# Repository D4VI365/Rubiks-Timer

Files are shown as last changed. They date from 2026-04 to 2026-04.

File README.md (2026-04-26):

# Rubiks Timer
I'm gonna build a timer to use with my rubiks cube, it will be powered by an esp32 and it will host a webpage to view the times registered.

The device is powered by a rechargable 2000mAh LiPo battery, it shows the time to the millisecond and the status of the timer with a strip of neopixels. There also are two phisical buttons for an easier access to deleting the time and adding a penality.

Full timer:
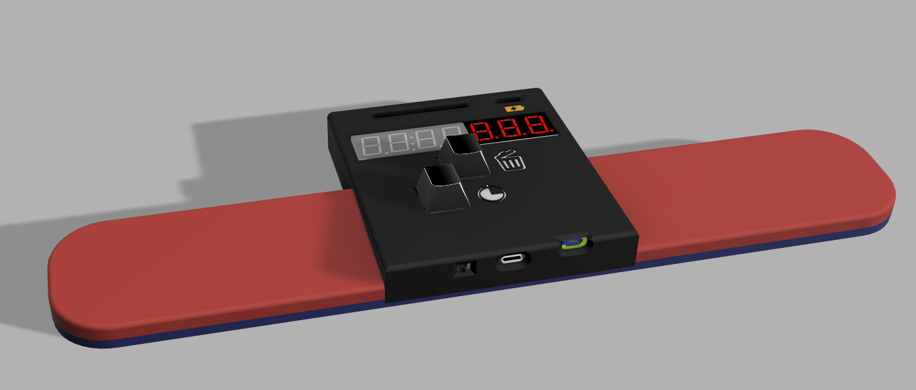
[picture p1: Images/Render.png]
Render


Electrical scheme:
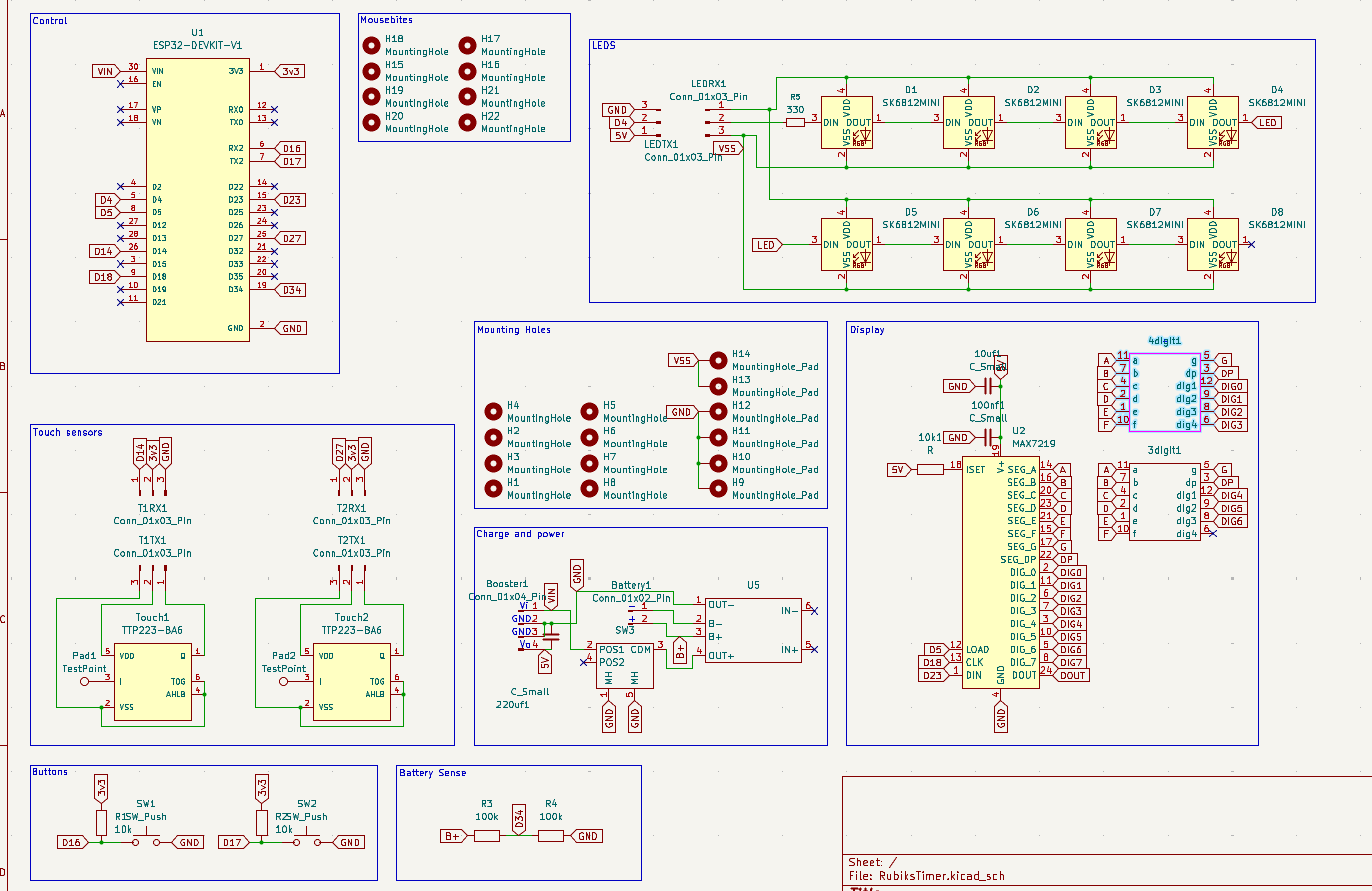
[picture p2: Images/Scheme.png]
Scheme


PCB layout: 
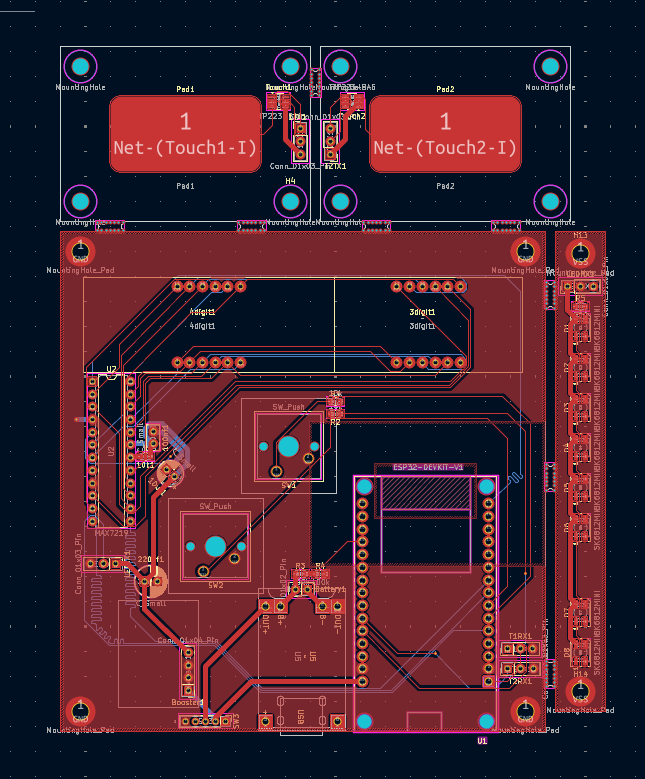
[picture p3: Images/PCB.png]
PCB


Inernal components placement:
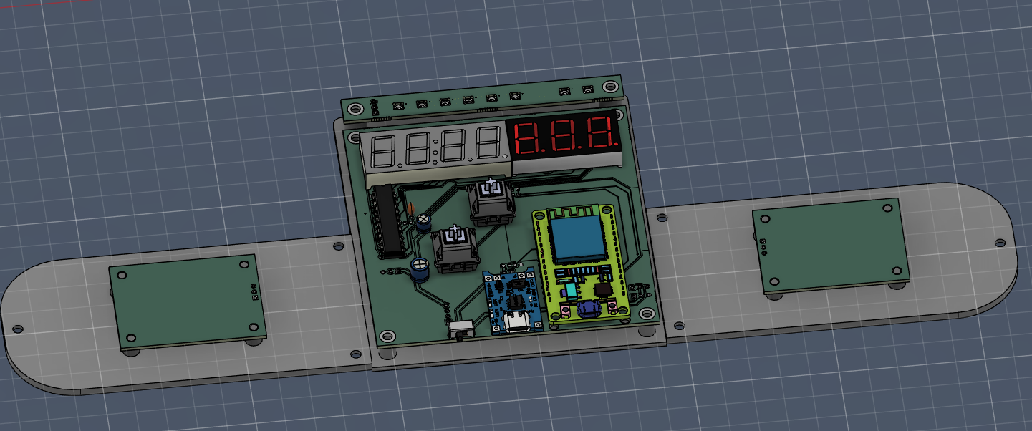
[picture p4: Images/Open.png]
Open


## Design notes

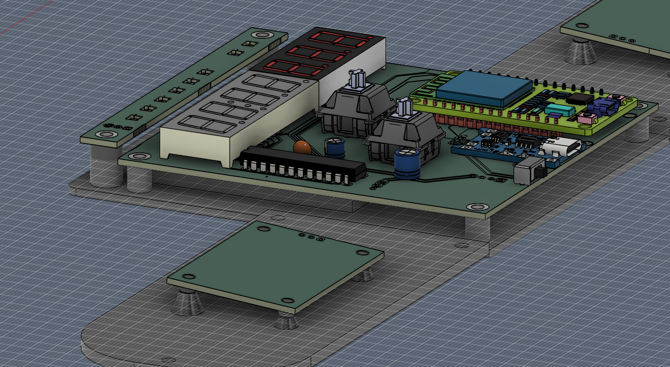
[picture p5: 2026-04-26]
Images/Side.png

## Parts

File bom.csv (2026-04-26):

Name | Purpose | Quantity | Total Cost (USD) | Link | Distributor
PCB | Holding the components | 1 | 10.00 | https://jlcpcb.com | JLCPCB
Neopixels | showing the battery and timer status | 5 | 4.02 | https://it.aliexpress.com/item/1005007576573654.html | Aliexpress
switches | Deleting times and adding penalities without opening the web page | 2 | 6.22 | https://it.aliexpress.com/item/1005007983672026.html | Aliexpress
505060 200mAh battery | powering the circuit off the grid | 1 | 11.26 | https://www.aliexpress.com/item/1005009145417769.html?spm=a2g0o.cart.0.0.685518fcIZnX3J&mp=1 | Aliexpress
TTP223 chip | creating the touch pads | 2 | 1.89 | https://www.aliexpress.com/item/1005006232332977.html?spm=a2g0o.cart.0.0.685518fcIZnX3J&mp=1 | Aliexpress
ESP32 | Controlling everithing | 1 | 4.71 | https://www.aliexpress.com/item/1005005953505528.html?spm=a2g0o.cart.0.0.685518fcIZnX3J&mp=1 | Aliexpress
2 digit 7segment display | Showing up to the cents of second | 1 | 1.70 | https://www.aliexpress.com/item/1005009575068782.html?spm=a2g0o.cart.0.0.685518fcIZnX3J&mp=1 | Aliexpress
MAX7219 | Controlling the 7segment displays | 1 | 3.88 | https://www.aliexpress.com/item/1005009392438551.html?spm=a2g0o.cart.0.0.685518fcIZnX3J&mp=1 | Aliexpress
5V boost module | getting 5V from the battry to power the ttp223 and the displays | 1 | 2.86 | https://www.aliexpress.com/item/1005006019647964.html?spm=a2g0o.cart.0.0.685518fcIZnX3J&mp=1 | Aliexpress
on off switch | cutting the circuit and preventing battery fading | 1 | 2.13 | https://www.aliexpress.com/item/1005010458551063.html?spm=a2g0o.cart.0.0.685518fcIZnX3J&mp=1 | Aliexpress
4digit 7segment display | showing minutes and seconds | 1 | 2.96 | https://www.aliexpress.com/item/1005009575068782.html?spm=a2g0o.cart.0.0.685518fcIZnX3J&mp=1 | Aliexpress
tp4056 | battery charging module | 1 | 1.54 | https://www.aliexpress.com/item/1005006043031985.html?spm=a2g0o.cart.0.0.685518fcIZnX3J&mp=1 | Aliexpress
smd resistors | Pull-up, protection and battery sensing circuit | 1 | 3.45 | https://www.aliexpress.com/item/1005002753179336.html?spm=a2g0o.cart.0.0.685518fcIZnX3J&mp=1 | Aliexpress
100nF capacitor | decoupling capacitors | 3 | 2.56 | https://www.aliexpress.com/item/1005007540183265.html?spm=a2g0o.cart.0.0.685518fcIZnX3J&mp=1 | Aliexpress

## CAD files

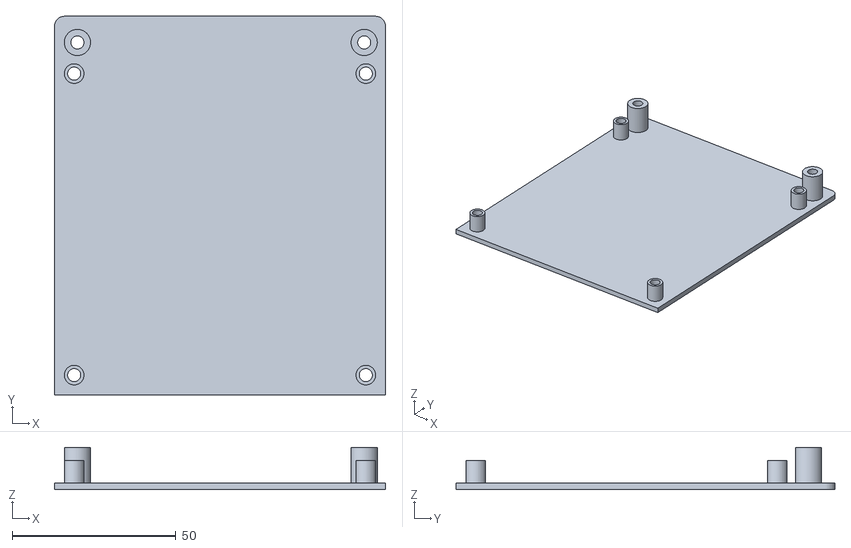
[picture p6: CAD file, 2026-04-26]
CAD/MainBottom.stl
101.0 x 115.5 x 13.0

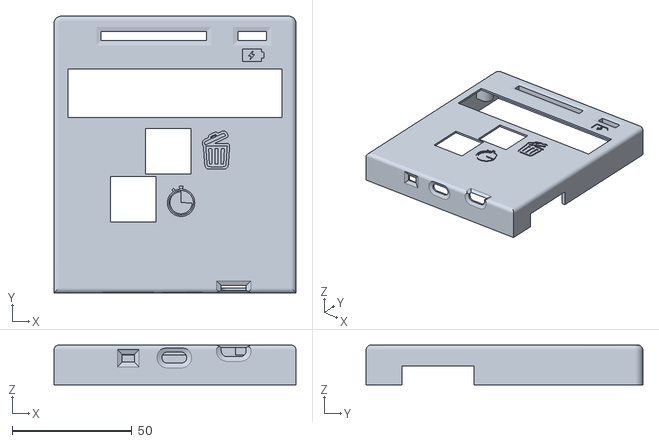
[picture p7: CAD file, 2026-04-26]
CAD/MainTop.stl
101.0 x 115.5 x 16.6

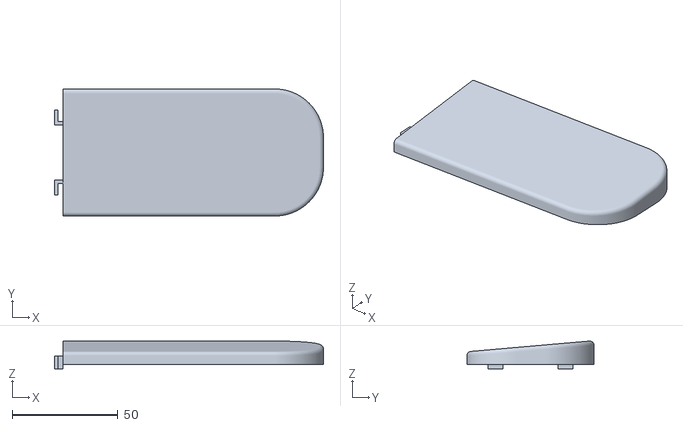
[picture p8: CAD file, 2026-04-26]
CAD/RightCAP.stl
127.0 x 60.0 x 13.2

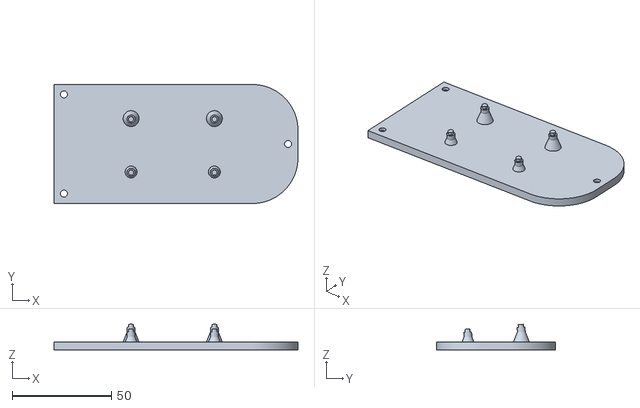
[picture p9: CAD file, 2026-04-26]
CAD/RightBottom.stl
123.0 x 60.0 x 12.9

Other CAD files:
CAD/LeftCAP.stl
CAD/LeftBottom.stl

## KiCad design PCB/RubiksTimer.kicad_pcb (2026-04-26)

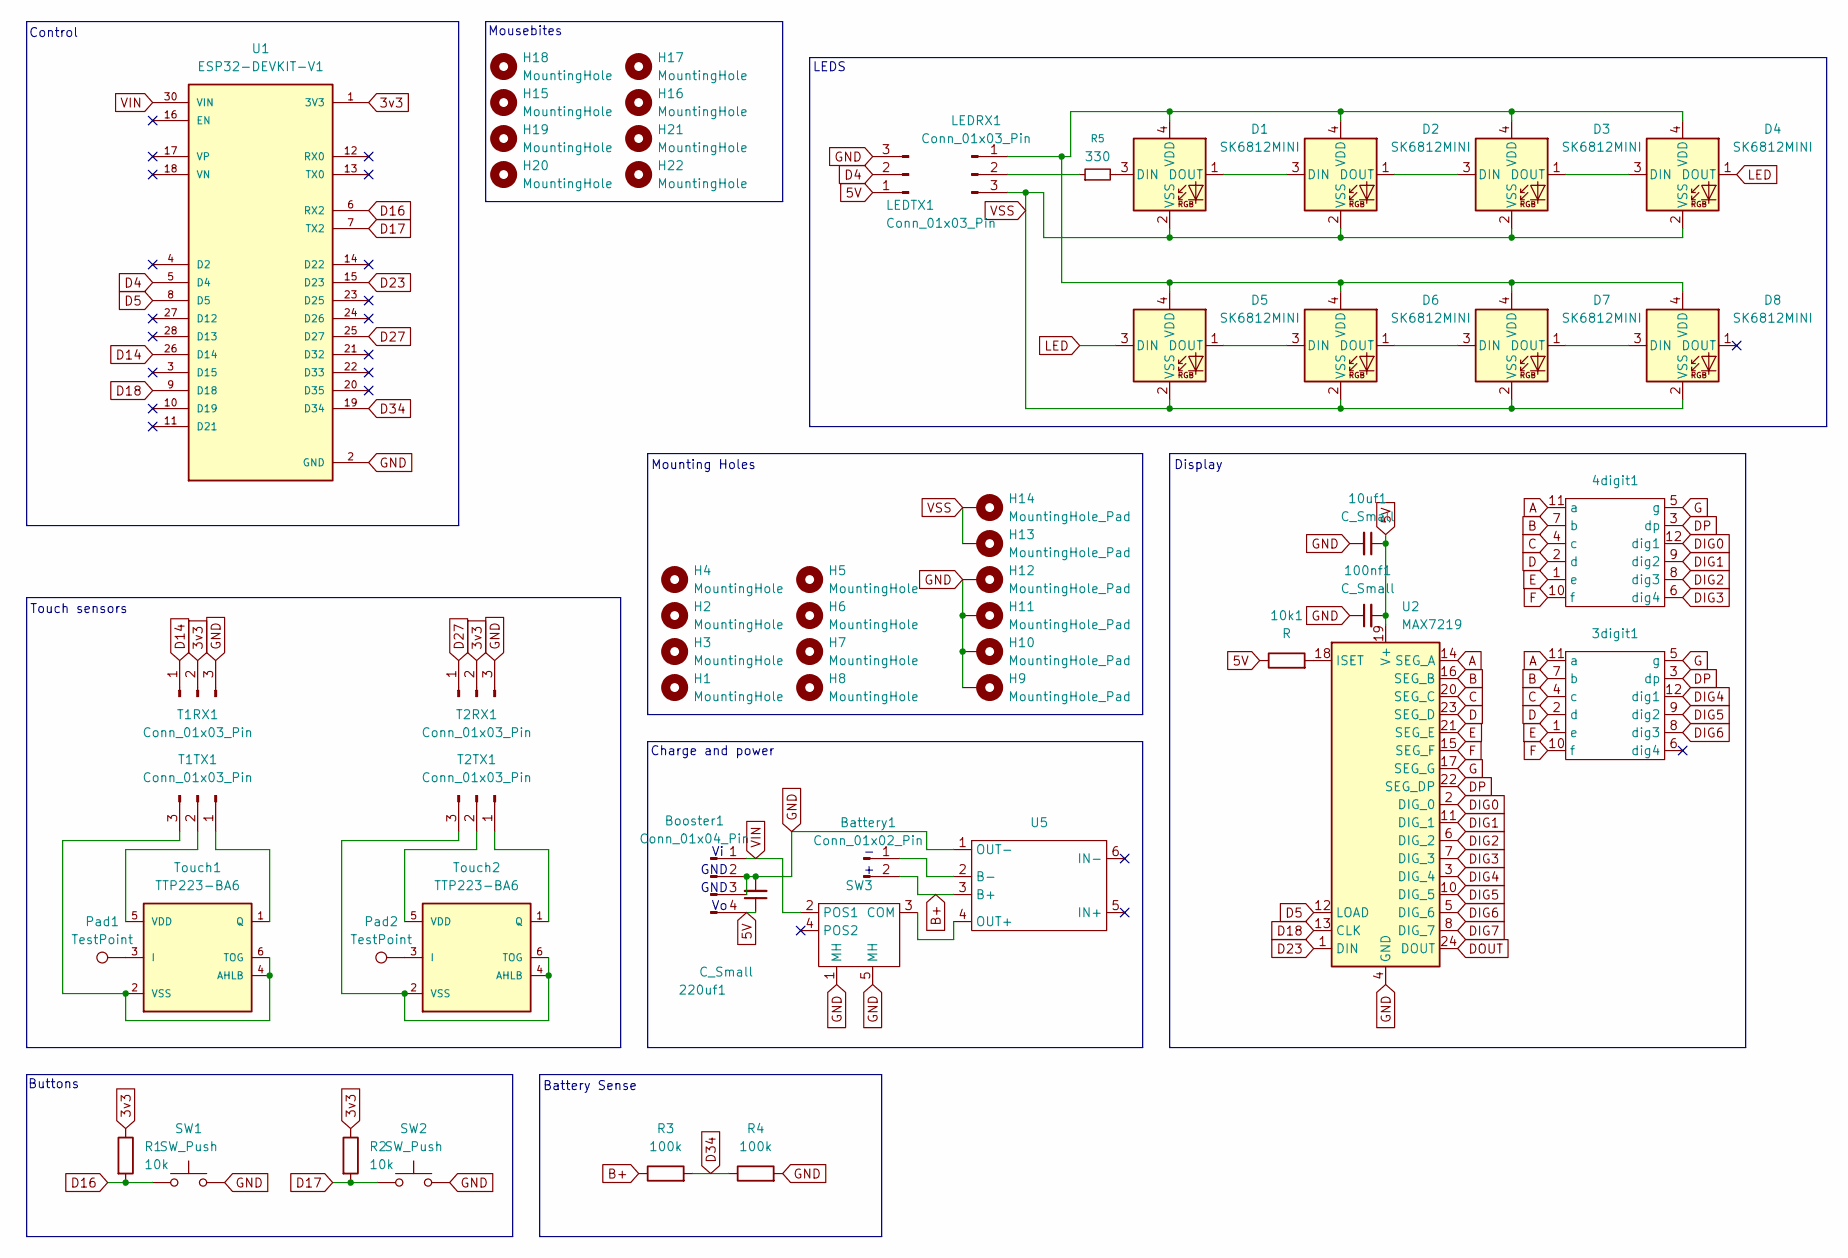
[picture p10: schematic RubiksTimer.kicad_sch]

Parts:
3digit1: 3dig CC display
4digit1: 4dig CC display
10k1: R; R_0805_2012Metric_Pad1.20x1.40mm_HandSolder
10uf1: C_Small; CP_Radial_D5.0mm_P2.00mm
100nf1: C_Small; C_Disc_D5.0mm_W2.5mm_P2.50mm
220uf1: C_Small; CP_Radial_D6.3mm_P2.50mm
Battery1: Conn_01x02_Pin; PinHeader_1x02_P2.54mm_Vertical
Booster1: Conn_01x04_Pin; PinHeader_1x04_P2.54mm_Vertical
D1, D2, D3, D4, D5, D6, D7, D8: SK6812MINI; MX_SK6812MINI-E
H1, H2, H3, H4, H5, H6, H7, H8: MountingHole; MountingHole_3.2mm_M3
H9, H10, H11, H12, H13, H14: MountingHole_Pad; MountingHole_3.2mm_M3_DIN965_Pad
H15, H16, H17, H18, H19, H20, H21, H22: MountingHole; Mousebite
LEDRX1: Conn_01x03_Pin; PinHeader_1x03_P2.54mm_Vertical
LEDTX1: Conn_01x03_Pin; PinHeader_1x03_P2.54mm_Vertical
Pad1, Pad2: TestPoint; 30x27pad
R1, R2: 10k; R_0805_2012Metric_Pad1.20x1.40mm_HandSolder
R3, R4: 100k; R_0805_2012Metric_Pad1.20x1.40mm_HandSolder
R5: 330; R_0805_2012Metric_Pad1.20x1.40mm_HandSolder
SW1, SW2: SW_Push; SW_Cherry_MX_1.00u_PCB
SW3: PinHeader_1x05_P2.00mm_Vertical
T1RX1, T1TX1, T2RX1, T2TX1: Conn_01x03_Pin; PinHeader_1x03_P2.54mm_Vertical
Touch1, Touch2: TTP223-BA6; SOT-23-6_Handsoldering
U1: ESP32-DEVKIT-V1; MODULE_ESP32_DEVKIT_V1; PARTREV N/A
U2: MAX7219; DIP-24_W7.62mm
U5: TP4056-protected

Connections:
3v3: R1.1, R2.1, T1RX1.2, T2RX1.2, U1.1 (3V3)
5V: 10k1.1, 10uf1.1, 100nf1.2, 220uf1.1, Booster1.4, LEDTX1.1, U2.19 (V+)
A: 3digit1.11 (a), 4digit1.11 (a), U2.14 (SEG_A)
B: 3digit1.7 (b), 4digit1.7 (b), U2.16 (SEG_B)
B+: Battery1.2, R3.1, U5.3 (B+)
C: 3digit1.4 (c), 4digit1.4 (c), U2.20 (SEG_C)
D: 3digit1.2 (d), 4digit1.2 (d), U2.23 (SEG_D)
D4: LEDTX1.2, U1.5 (D4)
D5: U1.8 (D5), U2.12 (LOAD)
D14: T1RX1.1, U1.26 (D14)
D16: R1.2, SW1.1, U1.6 (RX2)
D17: R2.2, SW2.1, U1.7 (TX2)
D18: U1.9 (D18), U2.13 (CLK)
D23: U1.15 (D23), U2.1 (DIN)
D27: T2RX1.1, U1.25 (D27)
D34: R3.2, R4.1, U1.19 (D34)
DIG0: 4digit1.12 (dig1), U2.2 (DIG_0)
DIG1: 4digit1.9 (dig2), U2.11 (DIG_1)
DIG2: 4digit1.8 (dig3), U2.6 (DIG_2)
DIG3: 4digit1.6 (dig4), U2.7 (DIG_3)
DIG4: 3digit1.12 (dig1), U2.3 (DIG_4)
DIG5: 3digit1.9 (dig2), U2.10 (DIG_5)
DIG6: 3digit1.8 (dig3), U2.5 (DIG_6)
DIG7: U2.8 (DIG_7)
DOUT: U2.24 (DOUT)
DP: 3digit1.3 (dp), 4digit1.3 (dp), U2.22 (SEG_DP)
E: 3digit1.1 (e), 4digit1.1 (e), U2.21 (SEG_E)
F: 3digit1.10 (f), 4digit1.10 (f), U2.15 (SEG_F)
G: 3digit1.5 (g), 4digit1.5 (g), U2.17 (SEG_G)
GND: 10uf1.2, 100nf1.1, 220uf1.2, Booster1.2, Booster1.3, H9.1 (1_1), H10.1 (1_1), H11.1 (1_1), H12.1 (1_1), LEDTX1.3, R4.2, SW1.2, SW2.2, SW3.1 (MH), SW3.5 (MH), T1RX1.3, T2RX1.3, U1.2 (GND), U1.29 (GND), U2.4 (GND), U2.9 (GND), U5.1 (OUT-)
LED: D4.1 (DOUT), D5.3 (DIN)
unnamed: Battery1.1, U5.2 (B-)
unnamed: D1.3 (DIN), R5.2
unnamed: D1.1 (DOUT), D2.3 (DIN)
unnamed: D1.4 (VDD), D2.4 (VDD), D3.4 (VDD), D4.4 (VDD), D5.4 (VDD), D6.4 (VDD), D7.4 (VDD), D8.4 (VDD), LEDRX1.1
unnamed: D2.1 (DOUT), D3.3 (DIN)
unnamed: D3.1 (DOUT), D4.3 (DIN)
unnamed: D5.1 (DOUT), D6.3 (DIN)
unnamed: D6.1 (DOUT), D7.3 (DIN)
unnamed: D7.1 (DOUT), D8.3 (DIN)
unnamed: LEDRX1.2, R5.1
unnamed: SW3.3 (COM), U5.4 (OUT+)
unnamed: T1TX1.1, Touch1.1 (Q)
unnamed: T1TX1.2, Touch1.5 (VDD)
unnamed: T1TX1.3, Touch1.2 (VSS), Touch1.4 (AHLB), Touch1.6 (TOG)
unnamed: T2TX1.1, Touch2.1 (Q)
unnamed: T2TX1.2, Touch2.5 (VDD)
unnamed: T2TX1.3, Touch2.2 (VSS), Touch2.4 (AHLB), Touch2.6 (TOG)
unnamed: Pad1.1 (1_1), Touch1.3 (I)
unnamed: Pad2.1 (1_1), Touch2.3 (I)
unnamed: 10k1.2, U2.18 (ISET)
VIN: Booster1.1, SW3.2 (POS1), U1.30 (VIN)
VSS: D1.2 (VSS), D2.2 (VSS), D3.2 (VSS), D4.2 (VSS), D5.2 (VSS), D6.2 (VSS), D7.2 (VSS), D8.2 (VSS), H13.1 (1_1), H14.1 (1_1), LEDRX1.3

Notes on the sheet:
LEDS
Mousebites
Display
Control
GND
Charge and power
Mounting Holes
Buttons
Touch sensors
Battery Sense

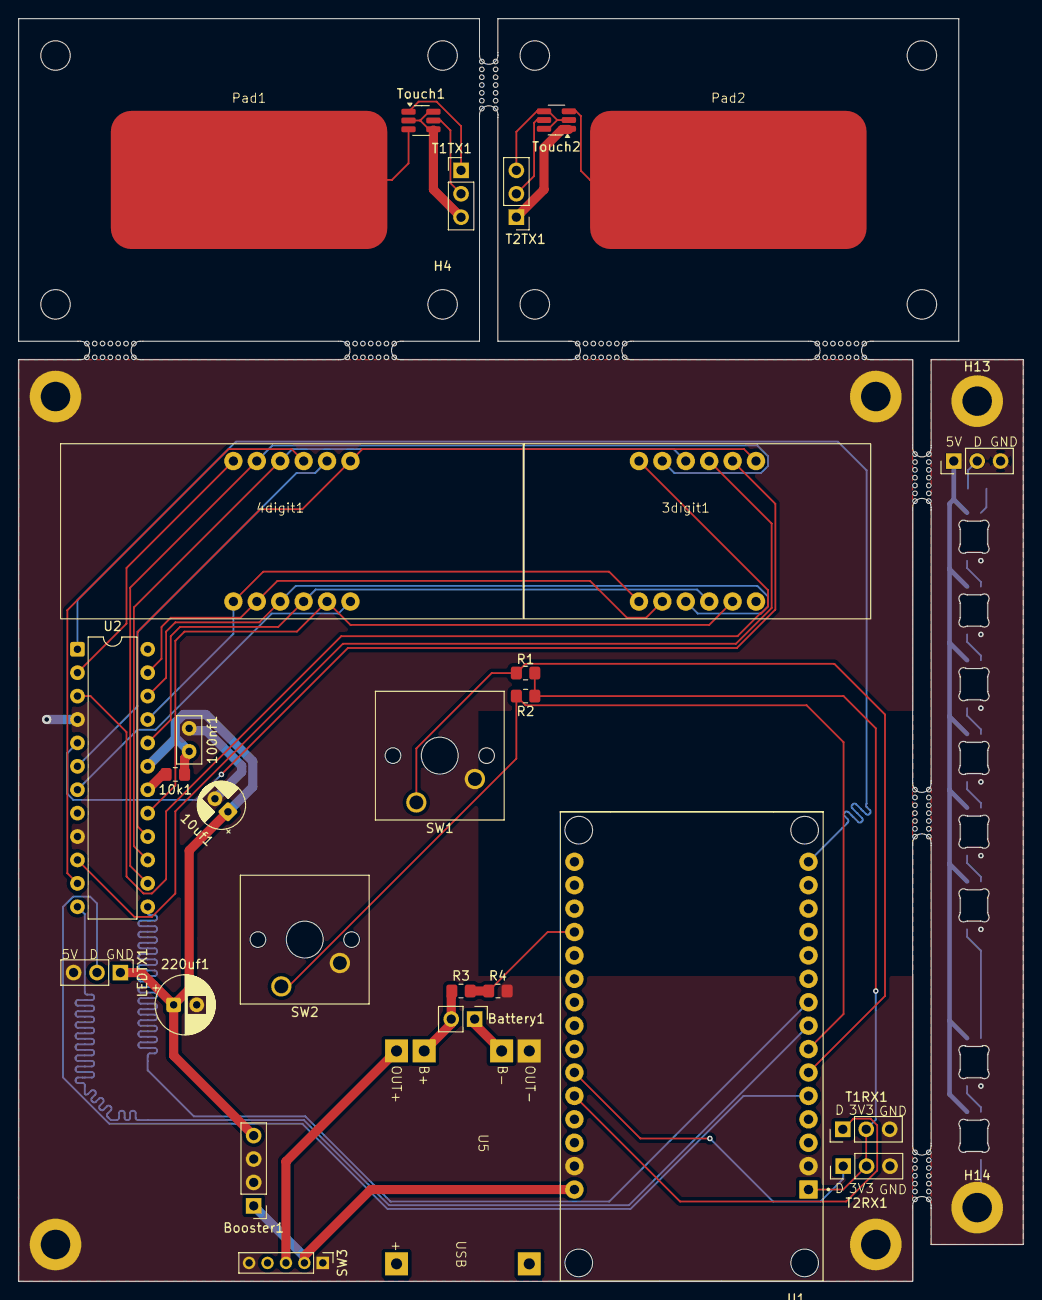
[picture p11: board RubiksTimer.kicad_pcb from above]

Board: 2 copper layers, 109.0 x 137.0 mm, 59 parts (1 on the bottom side), 51 nets.

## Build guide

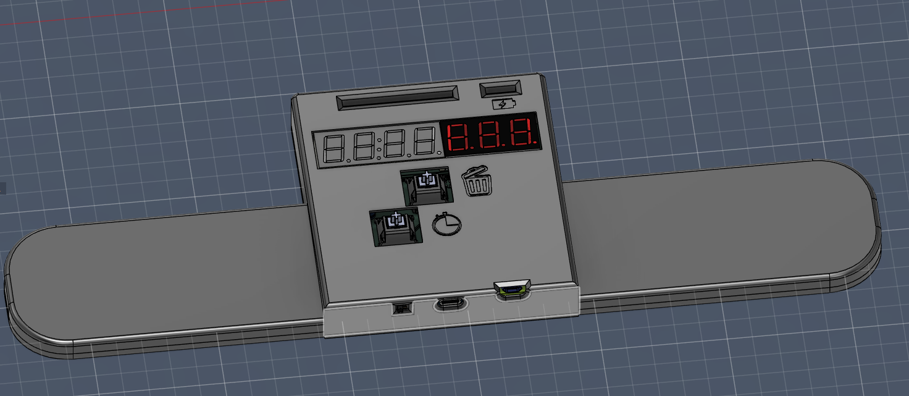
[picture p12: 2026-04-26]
Images/Assembly.png

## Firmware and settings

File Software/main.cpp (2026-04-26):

#include <LedControl.h>
#include <Adafruit_NeoPixel.h>

// --- CONFIGURAZIONE PIN ---
// MAX7219 (VSPI)
const int PIN_DIN = 23; 
const int PIN_CLK = 18;
const int PIN_LOAD = 5;

// Neopixel
const int PIN_LED = 4;
const int NUM_LEDS = 8;

// Touch e Bottoni
const int TOUCH_START = 14;
const int TOUCH_RESET = 27;
const int PIN_BATT = 34; // Analogico per partitore

// --- ISTANZE ---
LedControl lc = LedControl(PIN_DIN, PIN_CLK, PIN_LOAD, 1); // 1 chip MAX7219
Adafruit_NeoPixel strip(NUM_LEDS, PIN_LED, NEO_GRB + NEO_KHZ800);

// --- VARIABILI DI STATO ---
unsigned long startTime = 0;
unsigned long elapsedTime = 0;
bool running = false;

void setup() {
  Serial.begin(115200);
  
  // Inizializzazione MAX7219
  lc.shutdown(0, false);       // Esci dal risparmio energetico
  lc.setIntensity(0, 8);       // Luminosità media (0-15)
  lc.clearDisplay(0);          // Pulisci display
  
  // Inizializzazione Neopixel
  strip.begin();
  strip.show();                // Spegni tutto all'avvio
  
  // Configurazione Input
  pinMode(TOUCH_START, INPUT);
  pinMode(TOUCH_RESET, INPUT);
}

void loop() {
  checkInputs();
  
  if (running) {
    elapsedTime = millis() - startTime;
    updateLedsProgress();
  }
  
  displayTime(elapsedTime);
  delay(10); // Piccolo debouncing software
}

// --- LOGICA INPUT ---
void checkInputs() {
  // Start / Stop
  if (digitalRead(TOUCH_START) == HIGH) {
    delay(200); // Semplice debouncing
    if (!running) {
      startTime = millis() - elapsedTime;
      running = true;
    } else {
      running = false;
    }
    while(digitalRead(TOUCH_START) == HIGH); // Attende rilascio
  }

  // Reset
  if (digitalRead(TOUCH_RESET) == HIGH) {
    running = false;
    elapsedTime = 0;
    strip.clear();
    strip.show();
    while(digitalRead(TOUCH_RESET) == HIGH);
  }
}

// --- GESTIONE DISPLAY ---
void displayTime(unsigned long t) {
  // Calcola minuti, secondi, centesimi
  int minutes = (t / 60000) % 100;
  int seconds = (t / 1000) % 60;
  int centi = (t / 10) % 100;

  // Visualizzazione sui 7 segmenti (mappatura pin DIG0-DIG6)
  // Esempio: MM.SS.CC
  lc.setDigit(0, 6, minutes / 10, false);
  lc.setDigit(0, 5, minutes % 10, true); // Punto decimale
  lc.setDigit(0, 4, seconds / 10, false);
  lc.setDigit(0, 3, seconds % 10, true);
  lc.setDigit(0, 2, centi / 10, false);
  lc.setDigit(0, 1, centi % 10, false);
}

// --- GESTIONE LED ---
void updateLedsProgress() {
  // Esempio: un LED si accende ogni secondo che passa (fino a 8)
  int ledsToLight = (elapsedTime / 1000) % (NUM_LEDS + 1);
  
  for (int i = 0; i < NUM_LEDS; i++) {
    if (i < ledsToLight) {
      strip.setPixelColor(i, strip.Color(0, 255, 0)); // Verde
    } else {
      strip.setPixelColor(i, 0); // Spento
    }
  }
  strip.show();
}

// --- LETTURA BATTERIA (OPZIONALE) ---
float readBattery() {
  int raw = analogRead(PIN_BATT);
  // 4095 (12 bit) su 3.3V. Partitore 100k/100k (divide per 2)
  float voltage = (raw / 4095.0) * 3.3 * 2.0;
  return voltage;
}
